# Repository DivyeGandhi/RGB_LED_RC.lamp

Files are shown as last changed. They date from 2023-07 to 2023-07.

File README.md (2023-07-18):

# RGB_LED_RC.lamp
I am very Excited to show you all that for the mini project of Electronics Design Workshop, I Created a Remote controlled RGB Lamp with tunable RGB and brightness to make 16,777,216 colours. It also has an Auto adjust to room Brightness button to adjust the brightness which best suits the room.

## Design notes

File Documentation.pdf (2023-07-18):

## REMOTE CONTROL LED RGB LAMP WITH

## AUTO BRIGHTNESS ADJUSTER

### A project report submitted in partial fulfillment of the requirements

### for the award of the degree of

### B.TECH in

### Electronics And Communication Engineering

By

### ABHAY TIWARI (2021UEC2608)

### DHRUV SAINI (2021UEC2626)

### DIVYE GANDHI(2021UEC2638)

### Under the supervision of

### D.V GADRE

### ELECTRONICS AND COMMUNICATION ENGINEERING

### Netaji Subhas University of Technology, Delhi

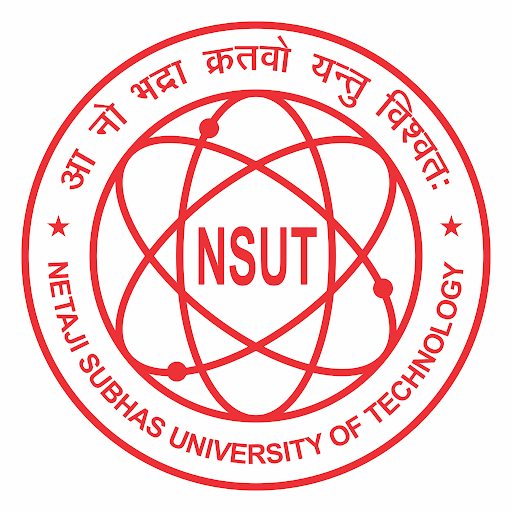
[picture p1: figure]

## DIVISION OF ELECTRONICS AND COMMUNICATION ENGINEERING NETAJI SUBHAS UNIVERSITY OF TECHNOLOGY

## DELHI-110078

## JANUARY-APRIL(2023)

### CERTIFICATE

This is to certify that the project titled REMOTE CONTROL LED RGB LAMP

WITH AUTO BRIGHTNESS ADJUSTER is a bonafide record of the work done by

ABHAY TIWARI(2021UEC2608)

DHRUV SAINI (2021UEC2626)

DIVYE GANDHI(2021UEC2638)

under my supervision and guidance in partial fulfillment of the requirements for the

award of the degree of Bachelor of Engineering in ELECTRONICS AND COMMU-

NICATION ENGINEERING of the Netaji Subhas Institute of Technology, Univer-

sity of Delhi, DELHI-110078, during the year 2023-2024.

Their work is genuine and has not been submitted for the award of any other degree

to the best of my knowledge.

DATE:

PROFESSOR NAME : D.V GADRE

Division of Electronics And Communication Engineering

Netaji Subhas Institute of Technology

### DECLARATION

This is to certify that the work which is being hereby presented by us in this project

titled “REMOTE CONTROL LED RGB LAMP WITH AUTO BRIGHTNESS

ADJUSTER” in partial fulfilment of the award of the Bachelor of Engineering submit-

ted at the Department of Information Technology, Netaji Subhas Institute of Technol-

ogy, University of Delhi, New Delhi, is a genuine account of our work carried out during

the period from August 2020 to December 2021 under the guidance of D.V.GADRE ,

Department of Electronics And Communication Engineering, Netaji Subhas Institute of

Technology, New Delhi.

The matter embodied in the project report to the best of our knowledge has not been

submitted for the award of any other degree elsewhere.

DATE:

Abhay Tiwari | 2021UEC2608
Dhruv Saini | 2021UEC2608
Divye Gandhi | 2021UEC2638

# Index

1. Introduction
(a) Description of Project
(b) Motivation
(c) Objectives
2. Components Description
(a) RTC Module - D53231
(b) ESP32
(c) Audio Board - PAMB-403
(d) Speaker
(e) LED Module - TM1637
3. Working
4. Designing
(a) Hardware Designing
(b) Software Designing and Code
5. Setup and Fabrication
(a) Board Layout Design
(b) PCB Fabrication
(c) Connecting the Components

(d) Outer Case
6. Conclusion and Future Developments
7. Bibliography

# Introduction

Throughout the ECE Lab portion, we learned a variety of electronic ideas, and we

practically all applied them to our EdW Lab project. Additionally, after learning a

lot from this course, we wanted to create a project that would push our academic and

intellectual limits. This paper includes a thorough overview of our invention, the ”Smart

LED Lamp,” a lamp that can be controlled remotely to change colour.

## DESCRIPTION

We aim to create a ’SMART RGB LED’ lamp that can be controlled by a TV remote.

The lamp will have the ability to change the intensity of red, blue, and green colors to

create the desired color output. It will also be capable of generating different patterns

that can be changed using the TV remote. Additionally, it will include an auto bright-

ness feature that can adjust the lamp’s intensity based on the room’s brightness. Finally,

the lamp will have a memory feature that allows it to remember the last color stored in

the lamp, in the event of a power outage. According to electronic theory, the project

will include all six blocks of electronic projects, as stated below:

1)Input Devices

2)Output Devices

3)Signal Processing

4)Data Visualization And storage

5)Communication with External World

6)Power Supply

# Motivation

During an interactive discussion with our professor D.V. Gadre, we decided to under-

take this project. The project is aimed at elderly people who may not have extensive

knowledge of technology. To make it accessible, we decided to use a TV remote control

as it is simpler than a mobile phone or other technologies. This Smart RGB lamp can

also be used as a home accessory, which is easy to use and interesting.

# Components List

### 1) Arduino Nano

Arduino Nano is a compact and user-friendly microcontroller board that is ideal for a

wide range of electronic projects. It is based on the ATmega328P microcontroller and

offers 14 digital input/output pins, 8 analog inputs, and 6 PWM pins. Additionally, it

has a built-in USB interface for programming and power supply purposes.

The small form factor of the Arduino Nano makes it easy to integrate into a wide

range of electronic devices, including small robots, home automation systems, and

wearable electronics. It is also an excellent choice for prototyping and experimenting

with new electronic projects.

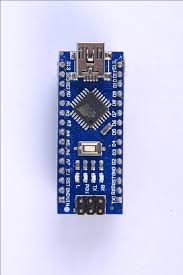
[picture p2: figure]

Figure 1: Arduino Nano board

### 2) TSOP1838 IR Receiver

The TSOP1838 is a miniature IR receiver IC from the TSOP18xx series. This particular

model TSOP1838 will respond to 38kHz IR signals from remote control devices. It is

normally used as an IR receiver in remote control applications like TV, AC, etc. This

version is small in size and hence can be used in compact devices.

The TSOP1838 is capable of receiving infrared signals from a distance of up to 10

meters and is compatible with most infrared remote control protocols.

TSOP1838 Features

- Operating Voltage: 2.5V to 5.5V
- Carrier Frequency (38kHz)
- Operating Current: 5mA
- High Range and Wide Coverage Area
- Improved Immunity Against HF and RF Noise
- Has Built-in Pre-Amplifier
- TTL and CMOS Compatible

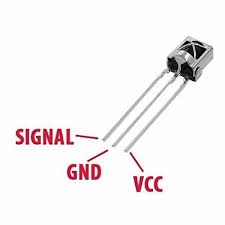
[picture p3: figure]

Figure 2: TSOP1838 IR receiver IC

### 3) LDR Sensor

An LDR (Light-Dependent Resistor) is a sensor that changes its resistance based on the

amount of light it is exposed to. LDRs are commonly used in light-sensing applications,

such as controlling streetlights or detecting when a room is occupied.

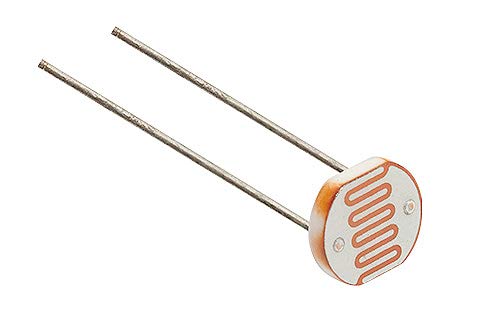
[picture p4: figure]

Figure 3: LDR sensor

### 4) LCD Display

An LCD (Liquid Crystal Display) is a type of flat panel display commonly used in

digital watches, calculators, and other electronic devices. They are also commonly

used in micro-controller based projects to display information, such as sensor readings

or system status.[Dimension of LCD:16X4]

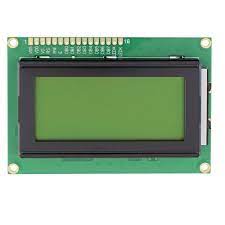
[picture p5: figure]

Figure 4: LCD display

# Working

### 1) Block Diagram

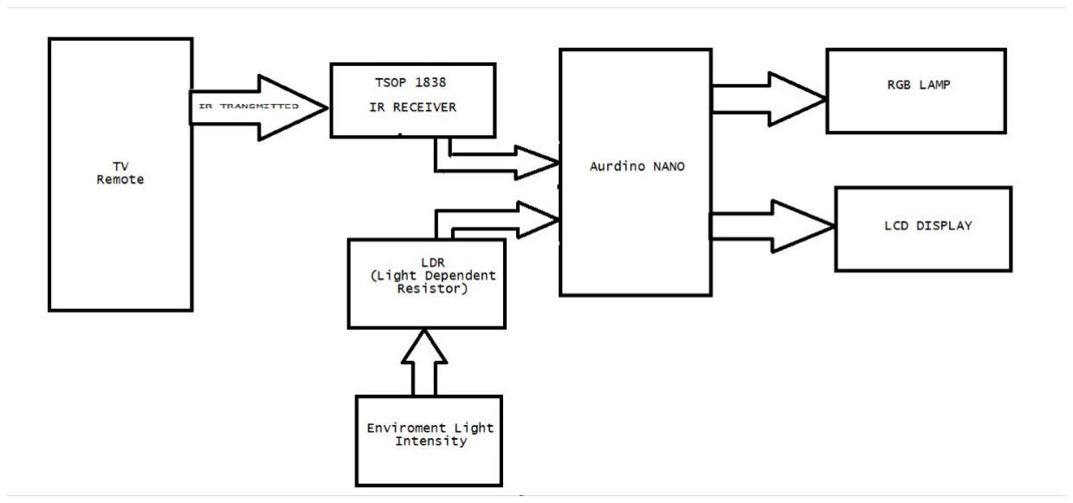
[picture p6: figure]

Figure 5: Block Diagram

# Designing

We will now move on to the designing phase, starting with drawing the schematic using

Eagle CAD software. After that, we will proceed to the PCB (Printed Circuit Board)

design layout.

### 1) Schematic Diagram :

To design the circuit for our SMART RGB LED Lamp, we used EAGLE CAD software.

The following image shows the complete circuit diagram for our project.

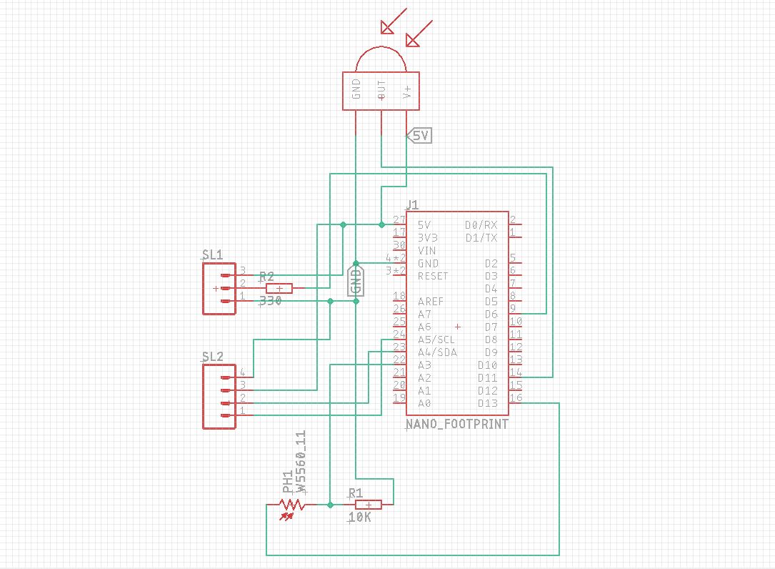
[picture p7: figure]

Figure 6: Block diagram of the system

### 2) Code Attachments :

#include <IRremote.h>

#include<EEPROM.h>

#include <Adafruit_NeoPixel.h>

#ifdef AVR

#include <avr/power.h> // Required for 16 MHz Adafruit Trinket

#endif

#include <LCD_I2C.h>

LCD_I2C lcd(0x27, 16, 4);

int RECV_PIN = 11;

IRrecv irrecv(RECV_PIN);

decode_results results;

Adafruit_NeoPixel pixels(170, 6, NEO_GRB + NEO_KHZ800);

float R=0,B=0,G=0;

float b=100;

void setup()

{

pixels.begin();

pinMode(6,OUTPUT);

pinMode(13,OUTPUT);

pinMode(A3,INPUT);

lcd.begin();

lcd.backlight();

Serial.begin(9600);

// In case the interrupt driver crashes on setup, give a clue

// to the user what’s going on.

Serial.println("Enabling IRin");

irrecv.enableIRIn(); // Start the receiver

Serial.println("Enabled IRin");

}

void writeEEPROM(int number , int address){

byte bytee=number;

EEPROM.write(address,bytee);

}

int readEEPROM(int address){

byte bytee=EEPROM.read(address);

return bytee;

}

void loop() {

// pulseWhite(5);

if (irrecv.decode(&results)) {

if(results.value==0xA70){

lcd.clear();

delay(500);

lcd.print("SET TO LAST SAVED COLOUR");

delay(500);

lcd.clear();

R=readEEPROM(18404);

G=readEEPROM(18405);

B=readEEPROM(18406);

for(int i=0; i<170; i++) {

pixels.setPixelColor(i, pixels.Color(R, G, B));

}

}

if(results.value==0xDD0){

lcd.clear();

delay(500);

lcd.print("SAVING COLOUR...");

delay(500);

lcd.clear();

writeEEPROM(R,18404);

writeEEPROM(G,18405);

writeEEPROM(B,18406);

}

else if(results.value==0x6CE9){

}

else if (results.value==0x2CE9){

colorWipe(pixels.Color(255, | 0, | 0), 50);

}

else if (results.value==0x1CE9){

whiteOverRainbow(75, 5);

}

else if(results.value==0xCD05 ){

if(b+10<=100)

{b=b+10;}

else{

b=100;

}

pixels.setBrightness(b);

}

else if(results.value==0xCD0){

if(b+10<=100)

{b=b+10;}

else{

b=100;

}

pixels.setBrightness(b);

}

else if(results.value==0x2D0){

if(b-10>0)

{b=b-10;}

pixels.setBrightness(b);

}

else if(results.value==0x10)

{

for(int i=0; i<170; i++) {

R=90;

G=0;

B=0;

pixels.setPixelColor(i, pixels.Color(R, G, B));

}

lcd.clear();

lcd.print("RED");

delay(500);

lcd.clear();

}

else if(results.value==0x810){

for(int i=0; i<170; i++) {

R=0;

G=90;

B=0;

pixels.setPixelColor(i, pixels.Color(R, G, B));

}

lcd.clear();

lcd.print("GREEN");

delay(500);

lcd.clear();

}

else if(results.value==0x410){

for(int i=0; i<170; i++) {

R=0;

G=0;

B=90;

pixels.setPixelColor(i, pixels.Color(R, G, B));

}

lcd.clear();

lcd.print("BLUE");

delay(500);

lcd.clear();

}

else if(results.value==0xC10){

for(int i=0; i<170; i++) {

R=0;

G=90;

B=90;

pixels.setPixelColor(i, pixels.Color(R, G, B));

}

lcd.clear();

lcd.print("AQUA");

delay(500);

lcd.clear();

}

else if(results.value==0x210){

for(int i=0; i<170; i++) {

R=90;

G=90;

B=0;

pixels.setPixelColor(i, pixels.Color(R, G, B));

}

lcd.clear();

lcd.print("YELLOW");

delay(500);

lcd.clear();

}

else if(results.value==0xA10){

for(int i=0; i<170; i++) {

R=90;

G=0;

B=90;

pixels.setPixelColor(i, pixels.Color(R, G, B));

}

lcd.clear();

lcd.print("PINK");

delay(500);

lcd.clear();

}

else if(results.value==0x610){

for(int i=0; i<170; i++) {

R=60;

G=60;

B=60;

R=R-7;

pixels.setPixelColor(i, pixels.Color(R, G, B));

}

lcd.clear();

lcd.print("WHITE");

delay(500);

lcd.clear();

}

else if(results.value==0xE10){

for(int i=0; i<170; i++) {

R=0;

G=90;

B=70;

pixels.setPixelColor(i, pixels.Color(R, G, B));

}

lcd.clear();

lcd.print("TERQUOISE");

delay(500);

lcd.clear();

}

else if(results.value==0x110){

for(int i=0; i<170; i++) {

R=90;

G=10;

B=0;

pixels.setPixelColor(i, pixels.Color(R, G, B));

}

lcd.clear();

lcd.print("ORANGE");

delay(500);

lcd.clear();

}

else if(results.value==0xA90){

for(int i=0; i<170 ; i++) {

lcd.clear();

R=0;

G=0;

B=0;

pixels.setPixelColor(i, pixels.Color(R, G, B));

}

lcd.clear();

lcd.print("LED OFF");

delay(500);

lcd.clear();

}

else if (results.value==0x490){

if(R+15<=90)

{R=R+15;}

else{

R=90;

}

for(int i=0; i<170; i++) {

pixels.setPixelColor(i, pixels.Color(R, G, B));

}

}

else if (results.value==0x90){

if(G+15<=90)

{G=G+15;}

else

{

G=90;

}

for(int i=0; i<170; i++) {

pixels.setPixelColor(i, pixels.Color(R, G, B));

}

}

else if (results.value==0x2F0){

if(B+15<=90){

B=B+15;

}

else{

B=90;

}

for(int i=0; i<170; i++) {

pixels.setPixelColor(i, pixels.Color(R, G, B));

}

}

else if(results.value==0x910){

for(int i=0; i<170; i++) {

R=80;

G=80;

B=60;

R=R-7;

pixels.setPixelColor(i, pixels.Color(R, G, B));

}

lcd.clear();

lcd.print("WARM WHITE");

delay(500);

lcd.clear();

}

else if (results.value==0xC90){

if(R-15>=0)

{R=R-15;}

else{

R=0;

}

for(int i=0; i<170; i++) {

pixels.setPixelColor(i, pixels.Color(R, G, B));

}

}

else if (results.value==0x890){

if(G-15>=0)

{G=G-15;}

else{

G=0;

}

for(int i=0; i<170; i++) {

pixels.setPixelColor(i, pixels.Color(R, G, B));

}

}

else if (results.value==0xAF0){

if(B-15>=0)

{B=B-15;}

else{

B=0;

}

for(int i=0; i<170; i++) {

pixels.setPixelColor(i, pixels.Color(R, G, B));

}

}

else if (results.value==0x290){

digitalWrite(13,HIGH);

float light=analogRead(A3);

lcd.clear();

lcd.print("ADJUST TO ROOM BRIGHTNESS =");

delay(900);

float vall=(1-(light/977))*100;

lcd.print(vall);

delay(900);

lcd.clear();

lcd.print(vall);

b=vall;

pixels.setBrightness(vall);

for(int i=0; i<170; i++) {

pixels.setPixelColor(i, pixels.Color(R, G, B));

// | pixels.show();
| }

}

| pixels.show();
| Serial.println(results.value, HEX);
| irrecv.resume(); // Receive the next value
| lcd.setCursor(0, 1);
// | lcd.print(results.value, HEX);
// | delay(900);
// | lcd.clear();
| lcd.clear();
| lcd.print("RED=");

// | lcd.setCursor(0, 1); // Or setting the cursor in the desired position.
| float val = (R/90.0)*100;
| lcd.print(val);
| lcd.print("%");
// | delay(250);
| lcd.setCursor(0, 1);
// | lcd.clear();
| lcd.print("GREEN=");
| val = (G/90.0)*100;
| lcd.print(val);
| lcd.print("%");
// | delay(250);
| lcd.setCursor(0, 2);
| lcd.print("BLUE=");
| val = (B/90.0)*100;
| lcd.print(val);
| lcd.print("%");
| lcd.setCursor(0, 3);
| lcd.print("BRIGHT.=");
| lcd.print(b);
| lcd.print("%");
// | delay(250);

}

delay(90);

}

void colorWipe(uint32_t color, int wait) {

for(int i=0; i<pixels.numPixels(); i++) { // For each pixel in strip...

pixels.setPixelColor(i, color); | // | Set pixel’s color (in RAM)

pixels.show(); | // | Update strip to match
delay(wait); | // | Pause for a moment

}

}

void whiteOverRainbow(int whiteSpeed, int whiteLength) {

if(whiteLength >= pixels.numPixels()) whiteLength = pixels.numPixels() - 1;

int | head | = whiteLength - 1;
int | tail | = 0;
int | loops | = 3;
int | loopNum | = 0;
uint32_t lastTime | = millis();

uint32_t firstPixelHue = 0;

for(;;) { // Repeat forever (or until a ’break’ or ’return’)

for(int i=0; i<pixels.numPixels(); i++) { | // For each pixel in strip...
if(((i >= tail) && (i <= head)) || | // | If between head & tail...

((tail > head) && ((i >= tail) || (i <= head)))) {

pixels.setPixelColor(i, pixels.Color(0, 0, 0, 255)); // Set white

} else { | | // else set rainbow

int pixelHue = firstPixelHue + (i * 65536L / pixels.numPixels());

pixels.setPixelColor(i, pixels.gamma32(pixels.ColorHSV(pixelHue)));

}

}

pixels.show(); // Update strip with new contents

// There’s no delay here, it just runs full-tilt until the timer and

// counter combination below runs out.

firstPixelHue += 40; // Advance just a little along the color wheel

if((millis() - lastTime) > whiteSpeed) { // Time to update head/tail?

if(++head >= pixels.numPixels()) { | // Advance head, wrap around

head = 0;

if(++loopNum >= loops) return;

}

if(++tail >= pixels.numPixels()) { | // Advance tail, wrap around

tail = 0;

}

lastTime = millis(); | // Save time of last movement

}

}

}

# Setup and Fabrication

### 1) Board Design Layout

We use Autodesk Eagle CAD in order to get board layout.The board layout is as follows:

We print this Layout on glossy paper and then it is used for PCB Fabrication

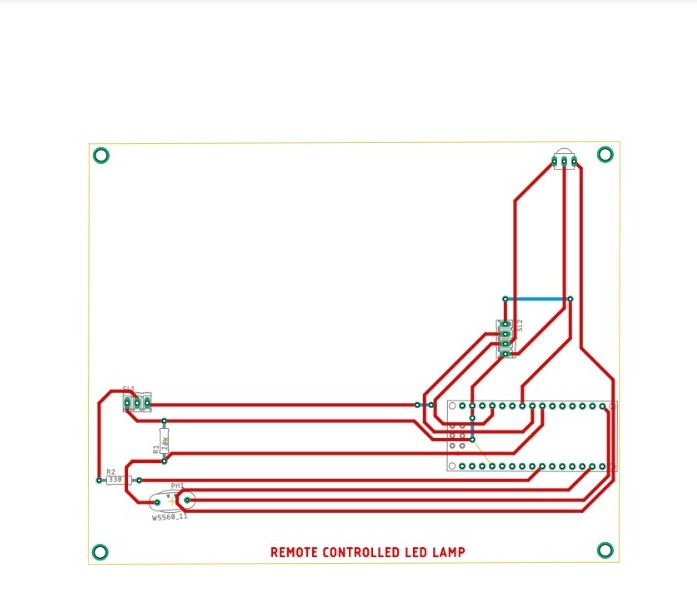
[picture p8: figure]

Figure 7: Board layout Design

### 2) PCB frabrication:

Following are the step of PCB Frabrication:

- Copper Clad Cutting: We use Shopbot machine in order to cut Copper Clad .The

Dimensions of copper clad is:

- Sanding And Filing: The copper surface that has been cut so far may have ac-

quired grooves and scratches, which could create issues during the process of

PCB (Printed Circuit Board) fabrication. To address this problem, sanding and

filling is performed on the copper clad.

- Pressing the board Layout with Iron: To transfer the layout onto the PCB, we

usually use a method called ”iron-on transfer.” This involves printing the layout

onto a special transfer paper and then using a hot iron to press the paper onto the

PCB, transferring the layout onto the board.

- Removing Paper: After pressing, we remove the paper from the PCB by dipping

it into the water.

- Etching: After removing paper ,we put PCB (Printed Circuit Board) in FeCl3

(Ferric Chloride) to etch away the copper that is not protected by the resist.The

resist is a protective layer applied to the copper surface to protect the desired

copper traces and pads from being etched away. When the PCB is placed in the

FeCl3 solution, the exposed copper that is not protected by the resist is chemically

etched away by the ferric chloride, leaving behind the copper traces and pads that

form the circuit pattern.After etching, the PCB is thoroughly cleaned and the

resist is removed, leaving only the copper traces and pads that form the circuit

pattern on the PCB.

- Drilling: Once we the board has been etched, it is drilled to create holes for the

components to be inserted.We drills holes using Drilling machine.

- Soldering: After drilling the components are solder on the board.After that nec-

essary wiring are done.

### 3) Outer Case:

After PCB fabrication and testing ,we make cutouts of Arcylic Sheets in order to make

Outer Case in Our Pcb: follows:

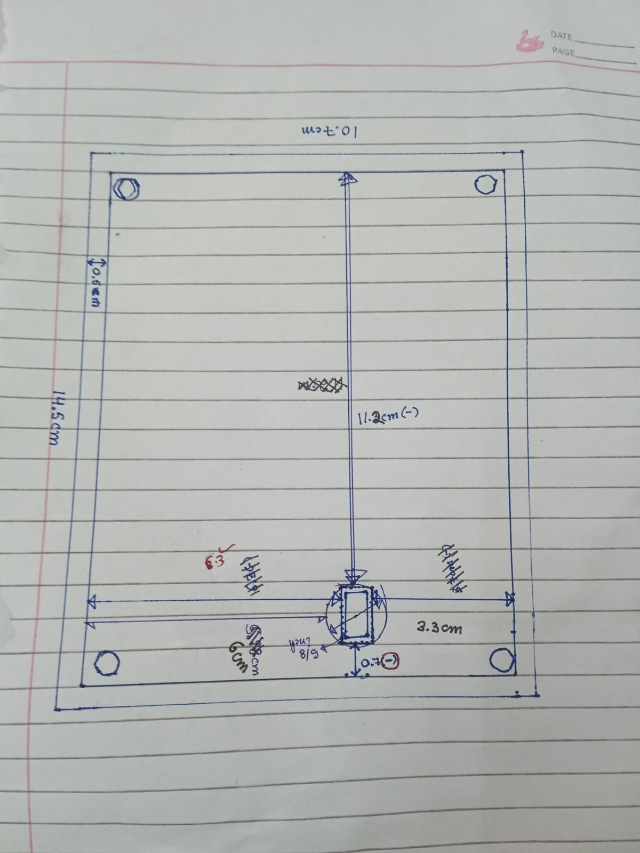
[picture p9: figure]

Figure 8: Dimension of outer case

# Conclusion

The fully functioning model of our project ”Smart LED Lamp ” has been successfully

developed with all functions working properly, it gives us all the feature that is discussed

in this project domentation.

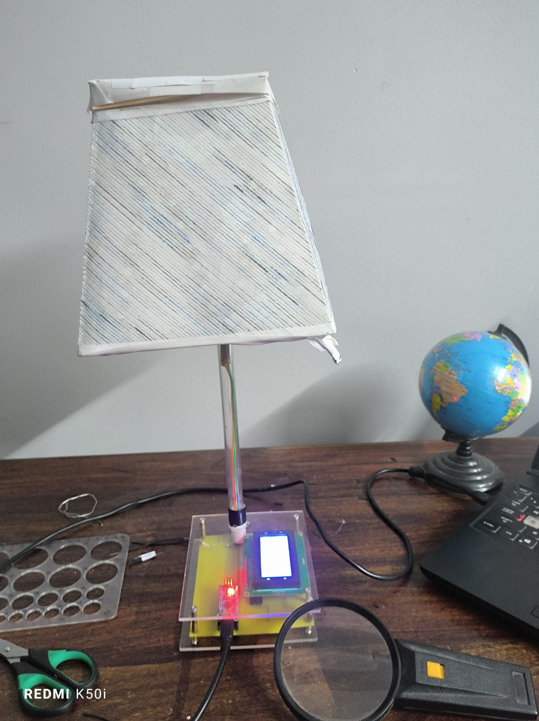
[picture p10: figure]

Figure 9: Block diagram of the system

# Bibliography

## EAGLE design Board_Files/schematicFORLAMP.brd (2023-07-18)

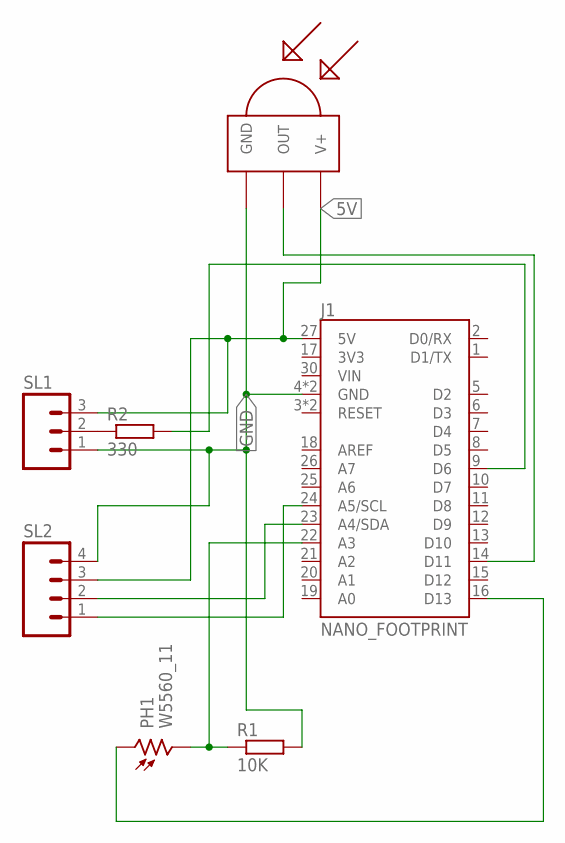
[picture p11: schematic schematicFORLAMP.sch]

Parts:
J1: NANO_FOOTPRINT; NANO
PH1: W5560_11; W55XX
R1: 10K; 0207/10
R2: 330; 0207/10
SL1: M03; 03P
SL2: M04; 04P
U$1: TSOP1838; TSOP18XX

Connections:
5V: J1.27 (5V), SL1.3, SL2.3, U$1.VCC (V+)
GND: J1.4 (GND), J1.29 (GND), R1.2, SL1.1, SL2.4, U$1.GND
unnamed: R2.1, SL1.2
unnamed: J1.9 (D6), R2.2
unnamed: J1.22 (A3), PH1.2, R1.1
unnamed: J1.14 (D11), U$1.OUT
unnamed: J1.16 (D13), PH1.1
unnamed: J1.23 (A4/SDA), SL2.2
unnamed: J1.24 (A5/SCL), SL2.1

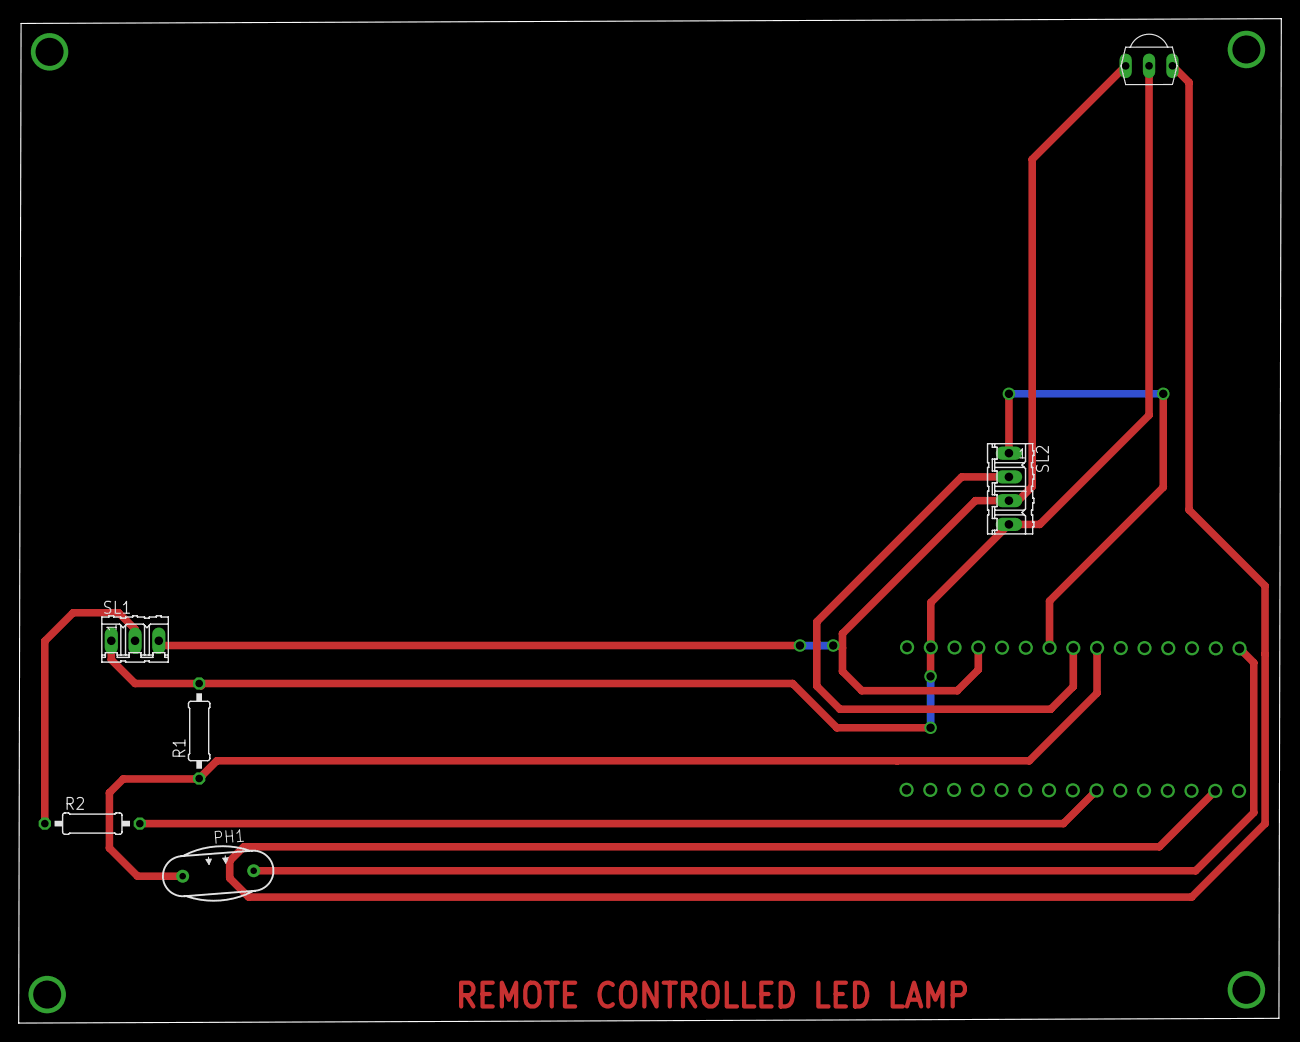
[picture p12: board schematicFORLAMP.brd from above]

Board: 2 copper layers, 135.1 x 107.4 mm, 7 parts (0 on the bottom side), 9 nets.

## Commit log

2023-07-18 Create added sketch.ino
    RGB Lamp with tunable RGB and brightness to make 16,777,216 colors, Auto adjust to room Brightness button to adjust the brightness which best suits the room , interesting patterns, the lamp can save 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
2023-07-18 Added Board Files
    [schematicFORLAMP.brd, schematicFORLAMP.sch]

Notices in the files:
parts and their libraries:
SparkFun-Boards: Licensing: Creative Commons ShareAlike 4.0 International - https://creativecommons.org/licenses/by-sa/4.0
